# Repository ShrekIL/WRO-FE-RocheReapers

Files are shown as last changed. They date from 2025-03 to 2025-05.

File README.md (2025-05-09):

#   RocheReapers Future Engineers Team

<p align="center">
  banner
</p>

This repository contains all the code and documentation of the WRO Team `RocheReapers`

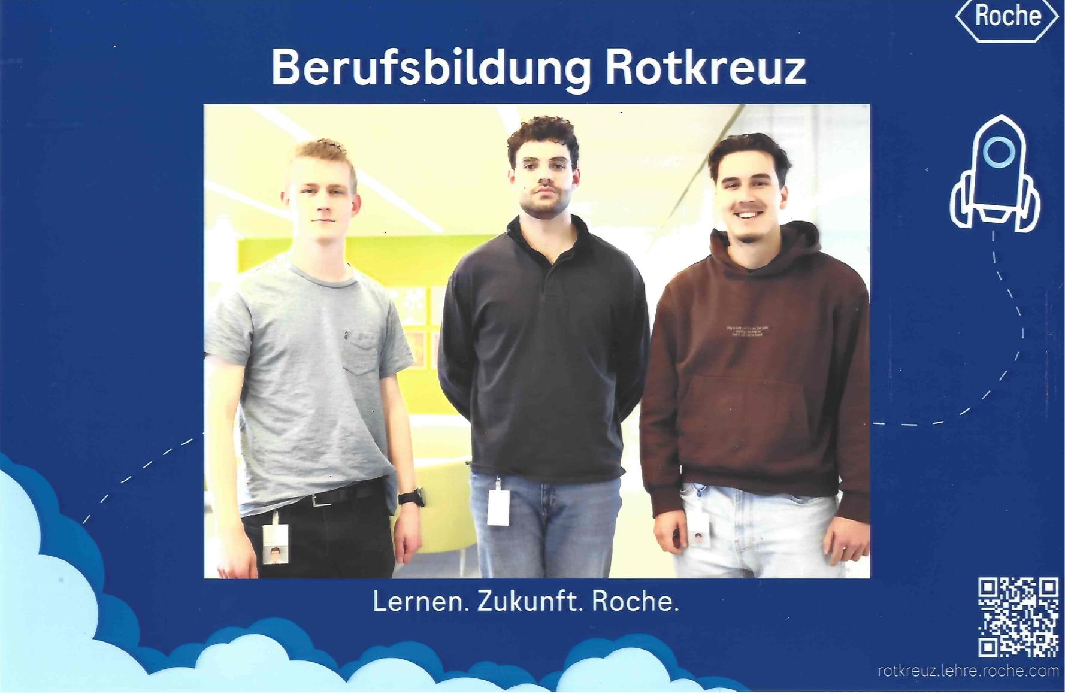
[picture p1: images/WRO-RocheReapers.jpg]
team_photo


**Team Members:**
\* [Robin Küttel](https://github.com/Robinkuet1): [robinkuettel@gmail.com](mailto:robinkuettel@gmail.com)
\* [Guilherme Vercillo Fortes](https://github.com/vercillg)
\* [Mischa Fässler](https://github.com/ShrekIL)

**Coach:**
\* Cyril Odermatt

##   Description of the developed solution

###   1. Problem Statement and Goal
The goal of the competition is to develop an autonomous vehicle that can complete two challenges:

-   Open Challenge: Three laps on a area of known size, but with a obstacle of unknown dimensions in the center.

-   Obstacle Challenge: Three laps with colored obstacles and a parallel parking maneuver in a parking zone on a 3x3 area.
    -   When <span style="color:red">red</span> obstacle =\> turn right
    -   When <span style="color:green">green</span> obstacle =\> turn left
    -   Parking zone colored with <span style="color:magenta">magenta</span>

---

###   2. Hardware Overview
The vehicle is based on the Hiwonder MentorPi A1.

####   Vehicle Photos

Below are the vehicle images from different perspectives.

<p align="center">
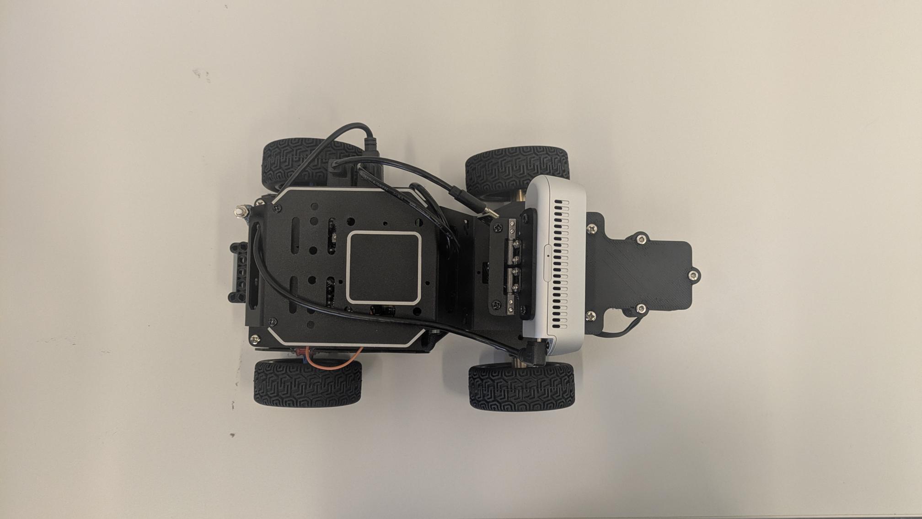
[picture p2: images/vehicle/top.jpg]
Top View

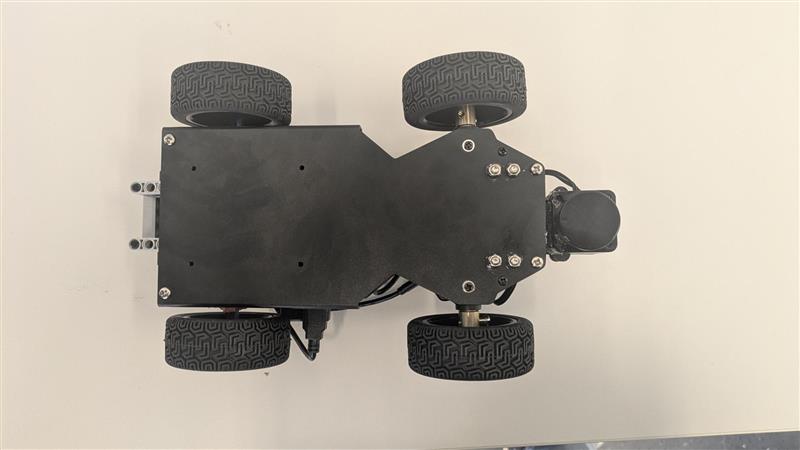
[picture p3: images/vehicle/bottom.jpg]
Bottom View

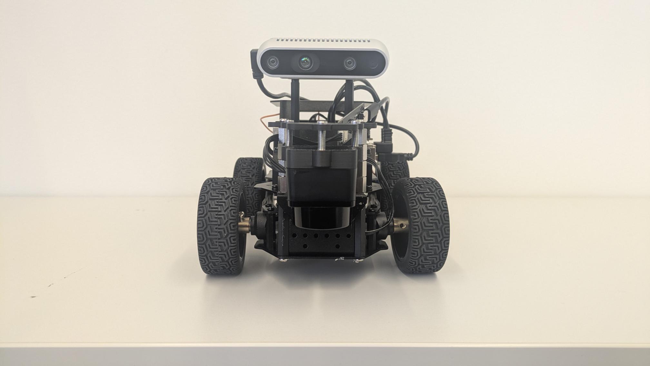
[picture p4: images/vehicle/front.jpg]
Front View

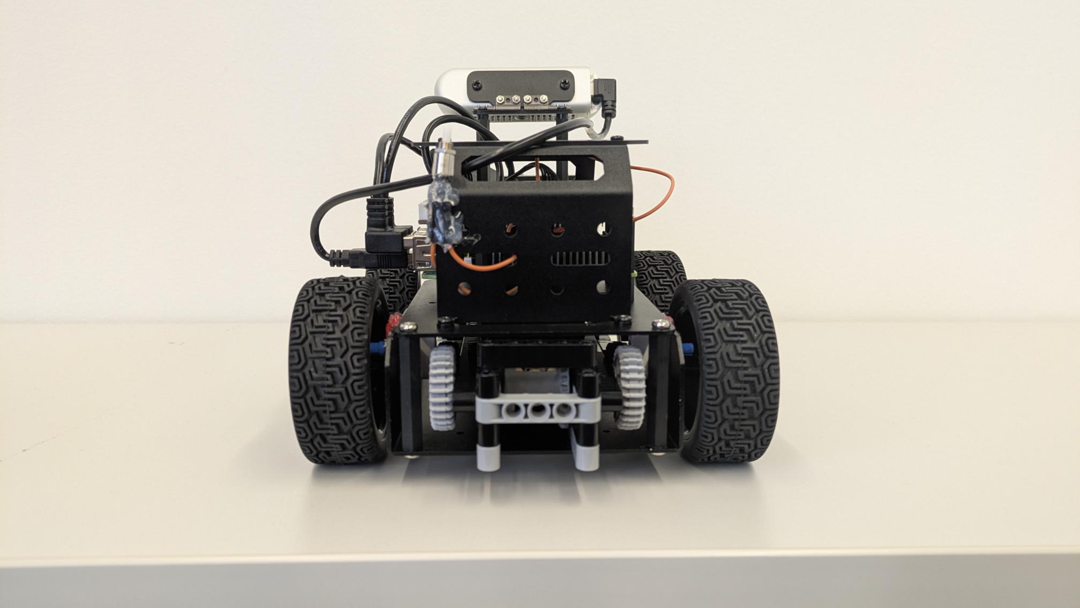
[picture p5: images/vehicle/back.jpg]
Back View

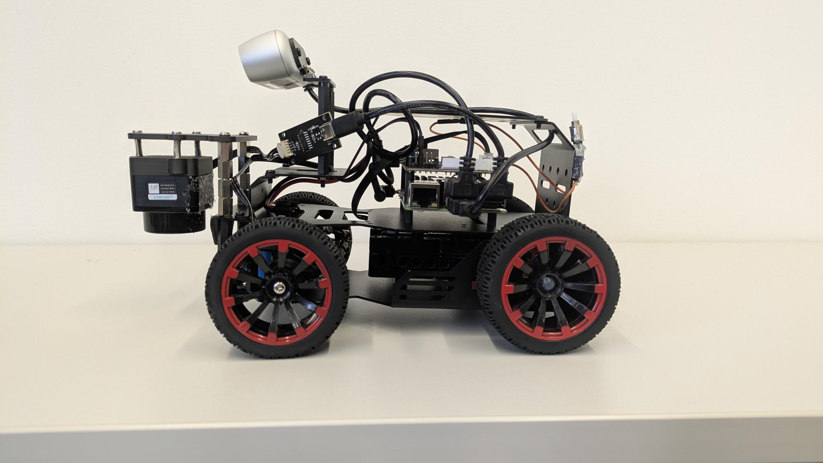
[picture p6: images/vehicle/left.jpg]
Left View

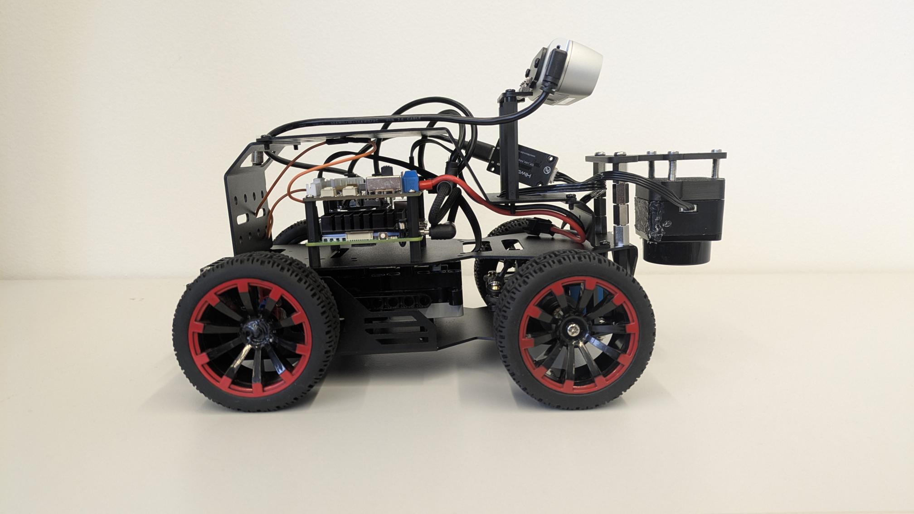
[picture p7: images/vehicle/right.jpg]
Right View

</p>

####   Hardware changes
We made the following hardware changes:

-   To comply with WRO rules, one motor was removed, so the drive is now powered by a single motor mechanically coupled to a LEGO differential gear. It also had to be stabilised with a lego construct for exact power output to the rear wheels.
-   The originally installed 3D camera was replaced with an Intel RealSense D435i to achieve a better performance. The brightness/colors of the original camera were too upredictable and thus not well suited for computer vision
-   The LiDAR sensor was relocated to the front of the vehicle, as the walls are only 10cm high. So the lidar is now at about 5cm above ground, for the highest possible chance to detect all the visible walls.
    -   Due to the repositioning of the LiDAR sensor, the camera's mounting height also had to be adjusted to maintain an unobstructed field of view. This was achieved by slightly elevating the camera using a custom riser.
-   The standard servo motor responsible for steering was replaced with a Power HD LW-15MG (waterproof) to significantly improve performance. The upgrade increased the control frequency from the standard 50 Hz to 333 Hz, resulting in faster and more precise steering response.
-   A simple push button was added to start the robot

####   Dimensions

| Parameter | Value |
|---:|---|
| Weight | 1.2 kg (on 3 attempts) |
| Height | 16.5 cm |
| Length | 28 cm |
| Width | 16.5 cm |

####   Lidar mounting
At first we tried to mount the lidar using hot glue. This didn't work well.
Due to the walls only beeing 10cm high and the lidar beeing mounted 5cm from the ground, we had 5cm of tolerance on a 3m distance.
If we calculate the anlge tolerance with trigonometry we get the following:

$sin(Tolerance) \* 3 = 0.05m$

If we solve this equation we arrive at:

$Tolerance\approx +-0.9549\textdegree$

We realized, that this is basically impossible to achieve with hot glue, we decided to design our own mounting mechanism.
For this we 3d printed a mount, that can be adjusted using 3 screws.

See following picture:

<p align="center">
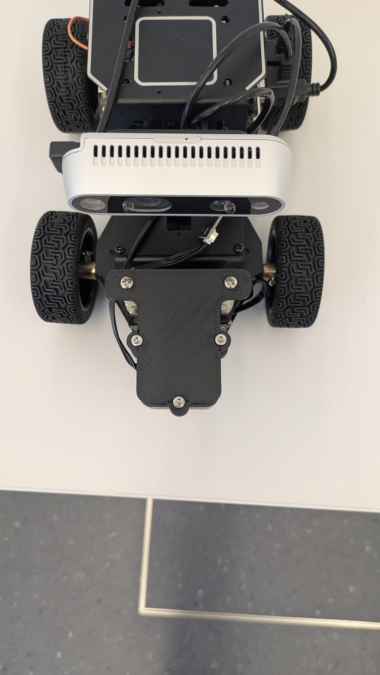
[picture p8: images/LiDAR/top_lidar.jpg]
top_lidar

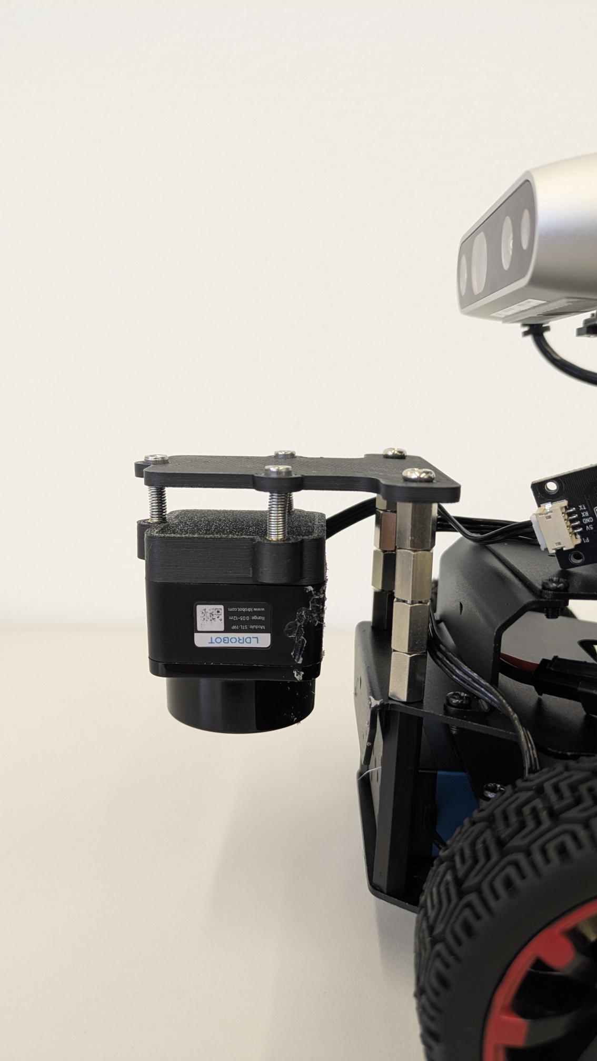
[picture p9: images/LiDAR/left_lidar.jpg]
left_lidar

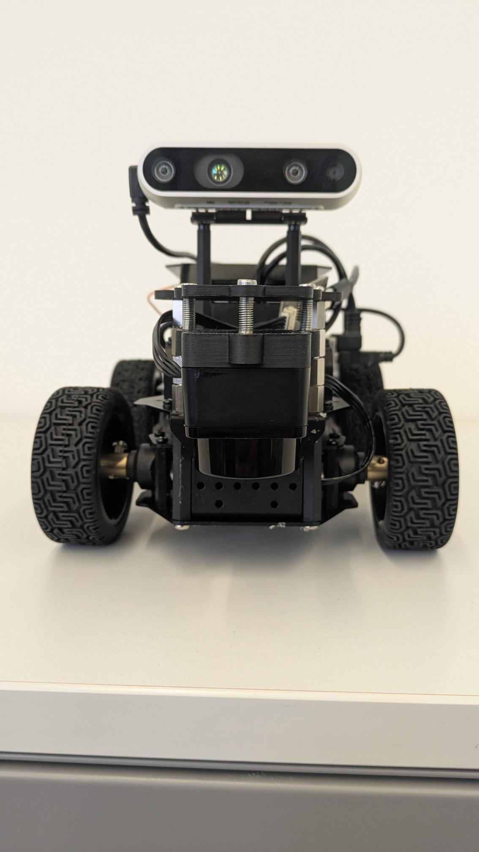
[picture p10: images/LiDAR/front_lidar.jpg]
front_lidar

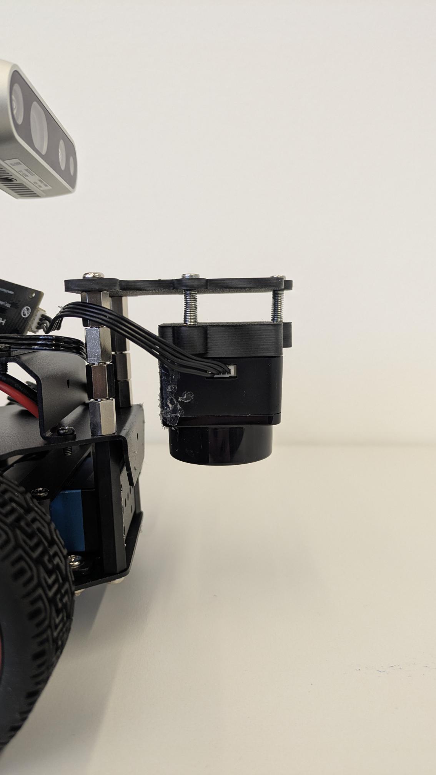
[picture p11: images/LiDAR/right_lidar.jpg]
right_lidar

<p>

With this, we were now able to accurately callibrate the lidar.

####   Lego differential gearbox

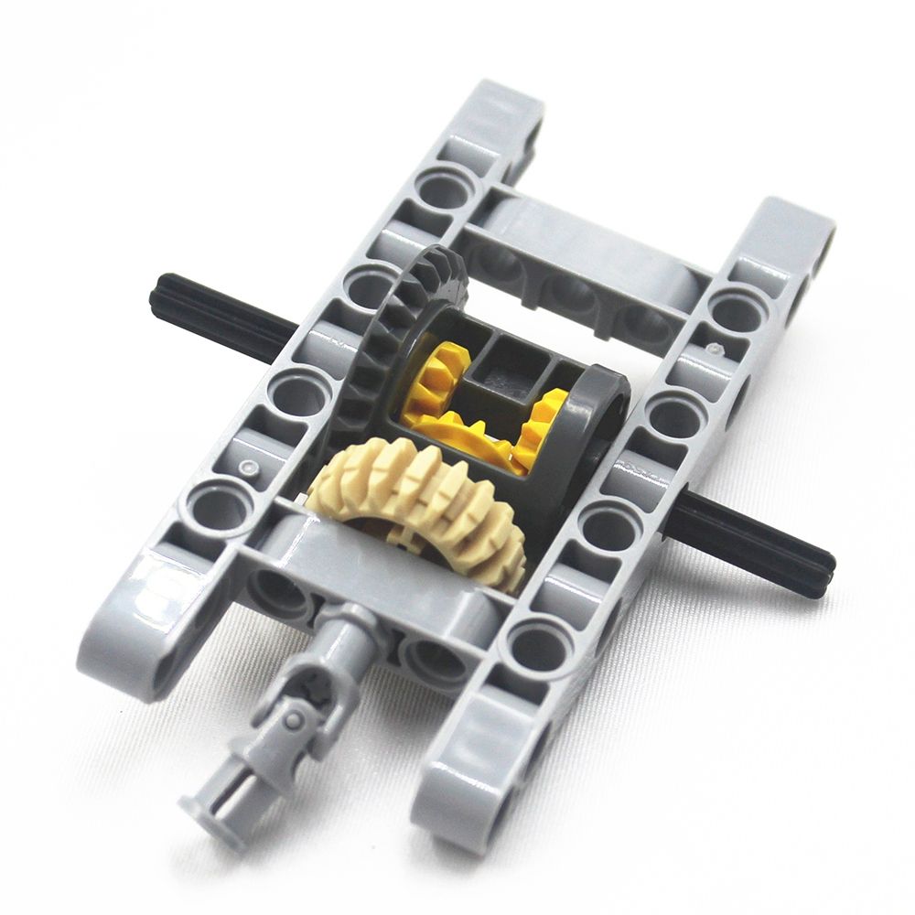
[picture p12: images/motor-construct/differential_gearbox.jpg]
differential_gearbox


Since the vehicle is now powered by a single motor, the use of a differential gearbox was essential. This allows the rear wheels to rotate at different speeds during turns, improving the robot's maneuverability and stability. The Lego construction was also stabilized to ensure precise and even power transmission to both rear wheels.

See following picture:

<p align="center">
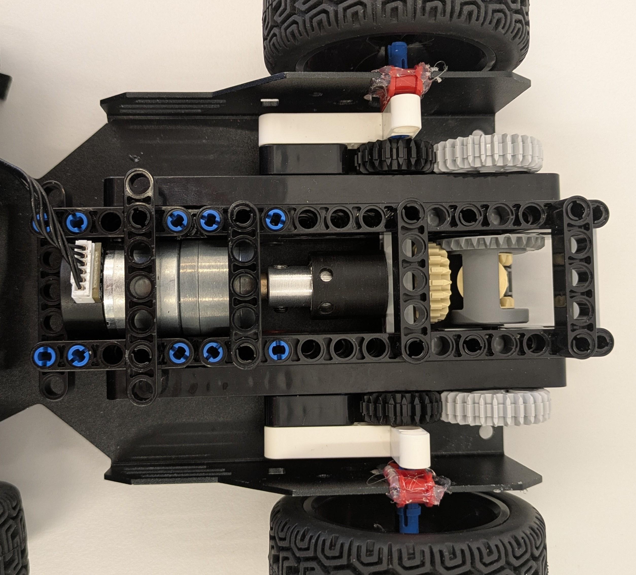
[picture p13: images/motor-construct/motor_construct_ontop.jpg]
motor_construct_ontop

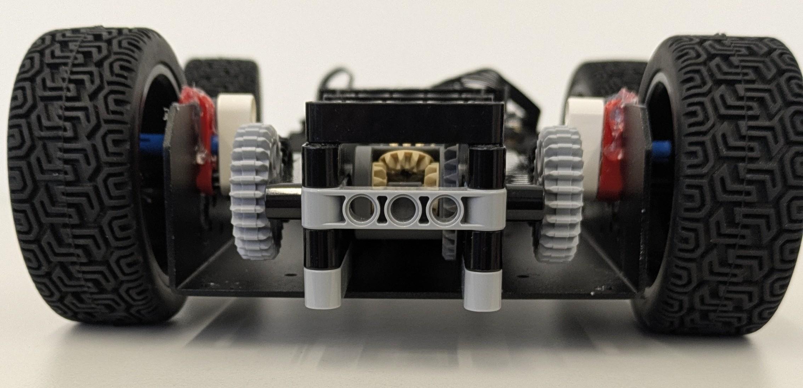
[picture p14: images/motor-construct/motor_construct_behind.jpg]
motor_construct_behind

<p>

####   Sensor Overview
| Component | Type/Model | Position on Robot | Function |
|---|---|---|---|
| 3D Camera | Intel RealSense D435i | Front (raised mount) | Color detection (OpenCV), depth sensing |
| LiDAR | STL-19P TOF Lidar | Front, 5 cm above ground | Obstacle/wall detection, navigation |
| Steering Servo | Power HD LW-15MG | Front axle | Controls steering (PWM, 333 Hz) |
| Drive Motor | Hiwonder DC Motor | Rear, center | Drives the vehicle via LEGO differential |
| Start Button | Generic Push Button | Top back left of chassis | Starts the program |

---

###   3. Software Overview

Our software works based on states that follow simple rules.

See the following diagram for an overview of the possible states:

```mermaid
stateDiagram-v2
[*] --> Ready
Ready --> Moving
Moving --> Turning
Turning --> Moving

Moving --> BackingUp
BackingUp --> Moving

Moving --> Parking
Moving --> [*]

Parking --> [*]
```

**Explanation of the states**:

**Ready**: The state right after powering the robot on. It waits and does nothing until the start button is pressed. Then the robot switches to the moving state.

**Moving**: This is the main state of the robot. In this state the robot just uses the lidar data to move around the 3x3 area.
In case a obstace is detected, the robot automatically starts turning into the direction corresponding to the color of the obstacle.
Whenever the distance of the robot to a wall in front gets below a certain threshold, it changes to the turning state.

**Turning**: In this state, the robot is turning in to the direction, where the wall is farther away.
As soon as the angle to the wall at the side and the front is close to 90deg, the state changes back to Moving.

**BackingUp**: In this state, the robot will try to move away from an obstacle while trying to turn a bit, so it is easier to pass the obstace when driving forward again.

####   Obstacle detection with OpenCV

**Goal**

To provide the robot with the capability to visually identify and locate red and green blocks, specifically for the **Obstacle Challenge.**
This supplements the LiDAR-based navigation used in the **Open Challenge** by adding color-based object recognition.

**Why OpenCV for this Task?**

**Color as a Key Feature**

The challenge involves colored obstacles. OpenCV allows us to easily isolate objects based on their color, providing a direct and efficient way to identify the target blocks.

**Complementary Sensing**
While LiDAR excels at distance measurement and obstacle avoidance, OpenCV provides semantic information about the type of obstacle (based on color).
Combining these sensor inputs allows for a more nuanced understanding of the environment.

**How it Integrates with the Robot's Software**

The OpenCV-based obstacle detection likely operates as a module within the robot's overall software architecture. It would:

-   **Process Images from the RealSense Camera:**
    The RealSense D435i, chosen for its improved color accuracy, provides the visual data that OpenCV analyzes.

-   **Identify Red and Green Regions:**
    Using the techniques described earlier (color space conversion, thresholding), OpenCV identifies areas in the image that match the defined red and green color ranges.

-   **Locate and Characterize Blocks:**
    By finding the contours of these colored regions, OpenCV can determine the position (in the image) and size of potential blocks. The color of each detected block can also be determined based on the dominant color within its contour.

-   **Provide Information to the Robot's State Machine:**
    The information about the detected blocks (their color, position, and size) is then likely passed to the robot's state machine.
    This allows the robot to make decisions and transition between states based on what it "sees."
    For example, upon detecting a green block in a specific area, the robot might initiate the parallel parking maneuver.

**Synergy with Other Sensors**

It’s important to note how the OpenCV-based detection works in conjunction with the LiDAR:

-   **LiDAR for General Obstacle Avoidance:**
    The LiDAR likely handles the primary task of navigating the 3×3 area and avoiding any unforeseen obstacles during both challenges.

-   **OpenCV for Color-Specific Tasks:**
    When the **"Obstacle Challenge"** requires interaction with colored blocks, OpenCV provides the necessary color identification capability that LiDAR alone cannot offer.

---

By integrating OpenCV for color-based object detection with the LiDAR for spatial awareness, the **RocheReapers' robot** gains a more comprehensive understanding of its environment, enabling it to tackle the complexities of both competition challenges effectively.

####   Development Tools & Libraries/SDKs

**Development Tools:**

-   **VS Code:** A widely used, free, and extensible code editor utilized for various programming languages and development tasks.

-   **PyCharm:** A dedicated Integrated Development Environment (IDE) specifically designed for Python development, offering advanced features for coding assistance, debugging, testing, and project management.

-   **Git:** A distributed version control system frequently used in software development to manage code changes and facilitate team collaboration. VS Code, for example, offers good integration with Git.

-   **GitHub:** A web-based hosting service for version control using Git that provides collaboration features such as bug tracking, feature requests, task management, and continuous integration. Used for sharing and collaborating on the robot's codebase.

-   **Intel RealSense Viewer:** A graphical tool for visualizing and configuring Intel RealSense depth cameras. It enables the display of depth, color, and infrared data, as well as the adjustment of camera settings.

-   **ROS (Robot Operating System):** A flexible framework for writing robot software. It provides a collection of tools, libraries, and conventions that aim to simplify the task of creating complex and robust robot behavior across a wide variety of robotic platforms. ROS often integrates with sensors like the Intel RealSense cameras.

-   **Linux:** A family of open-source Unix-like operating systems. It is known for its flexibility, customizability, and use in various applications, including development and server environments.

-   **Windows:** A series of graphical operating systems developed by Microsoft. It is widely used on personal computers and in enterprise environments.

-   **RealVNC Viewer:** A software application that allows you to control a remote computer over the network (can be used for remote development or accessing development environments).

**Libraries/SDKs:**

-   **Python:** A versatile and widely-used programming language in robotics for scripting, algorithm development, and integration with sensors and systems.

-   **OpenCV (`cv2`):** An open-source computer vision library used for image processing, object detection, and interfacing with camera streams.

-   **NumPy:** A powerful library for numerical operations on arrays, commonly used for image and sensor data processing.

-   **Matplotlib:** A plotting library used to visualize sensor data, debugging outputs, or robot trajectories during development.

-   **pyrealsense2:** Intel’s official Python wrapper for the librealsense SDK, used to interface with RealSense cameras for depth and RGB image capture.

-   **librealsense SDK:** A cross-platform library to interact with Intel RealSense cameras, including features like point cloud generation, depth alignment, and sensor fusion.

-   **pytest:** A testing framework for writing and running automated tests on Python code, useful for maintaining stable control and perception modules.

-   **ROS 2 Message Types & Services:**
    -   `sensor_msgs`, `geometry_msgs`, `std_srvs`, `ros_robot_controller_msgs`: ROS interfaces used for sensor data (e.g., images, laser scans), robot movement (Twist messages), service requests (e.g., enable/disable modules), and PWM servo control.

###   Videos
https://youtu.be/dnrOrvzk_1k?si=iM_9Jk8Tol_acwze

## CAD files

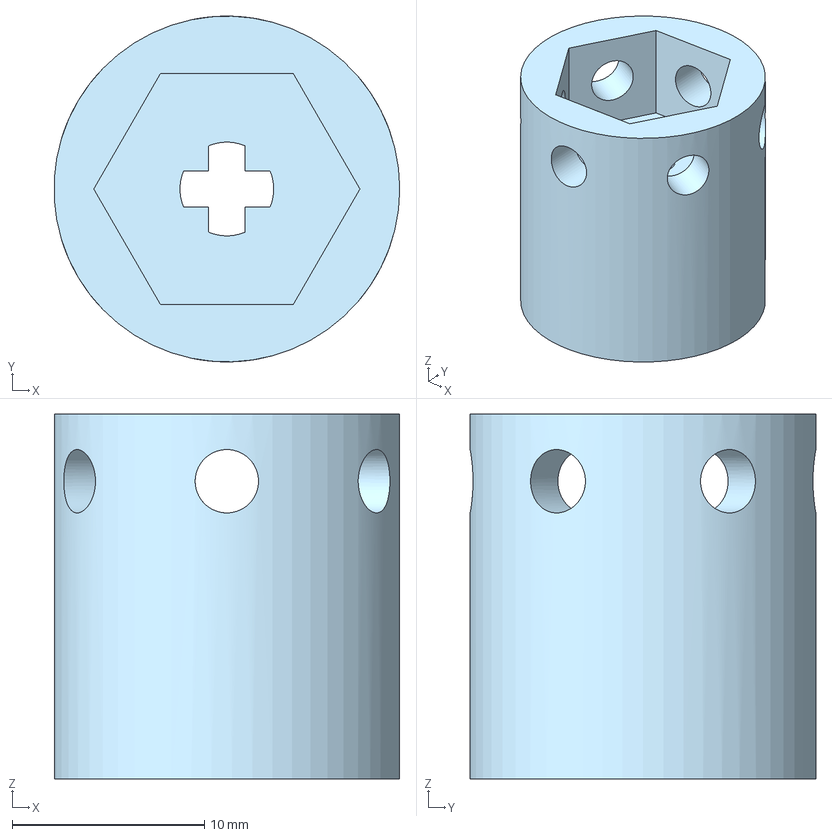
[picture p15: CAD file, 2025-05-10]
3d_models/Adapter_motorachse.step
18.0 x 18.0 x 19.0 mm

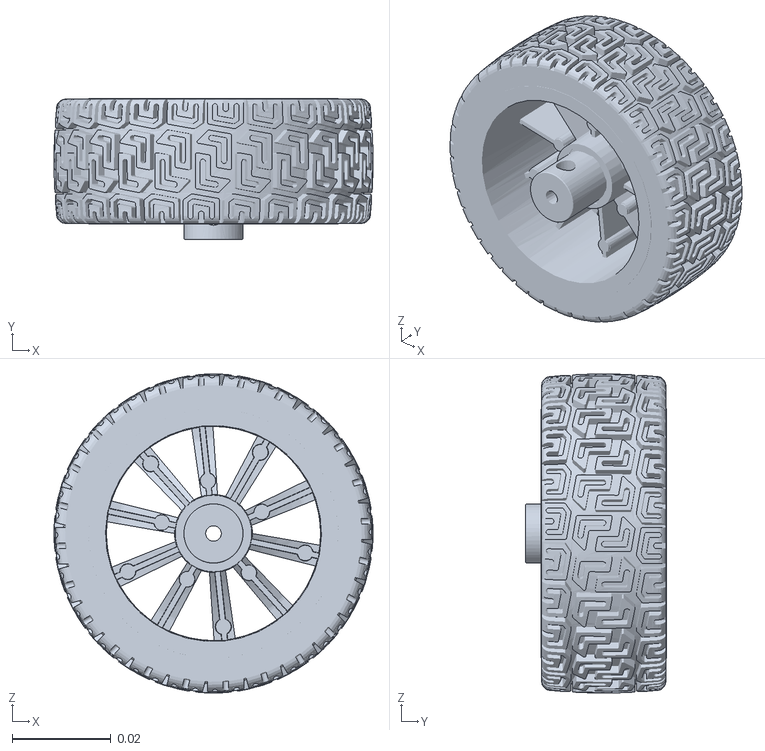
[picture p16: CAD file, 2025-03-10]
src/simulations/mentorpi_description/meshes/acker/wheel_lb_Link.STL
0.0647 x 0.0285 x 0.0647

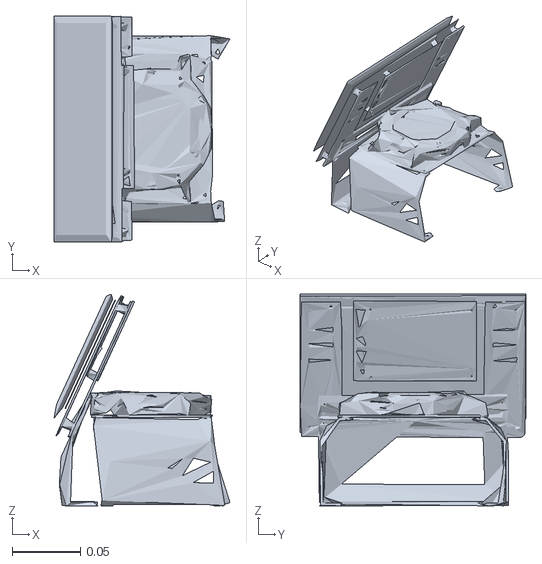
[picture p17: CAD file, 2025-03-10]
src/simulations/mentorpi_description/meshes/common/back_shell_black_link_collision.stl
0.129 x 0.165 x 0.155

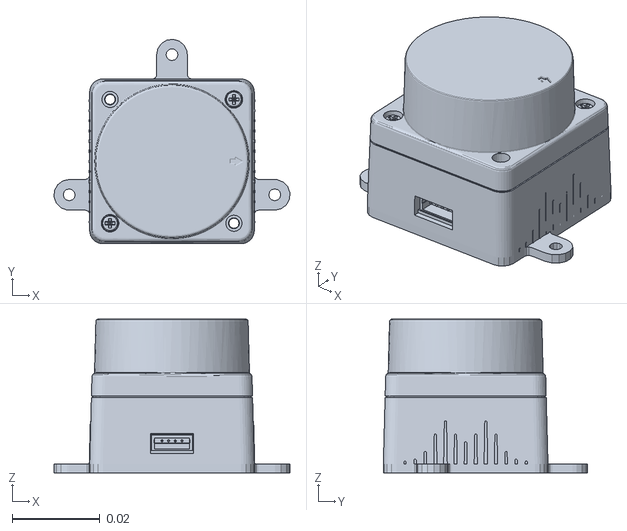
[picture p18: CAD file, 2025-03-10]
src/simulations/mentorpi_description/meshes/mecanum/lidar_Link.STL
0.0537 x 0.0465 x 0.035

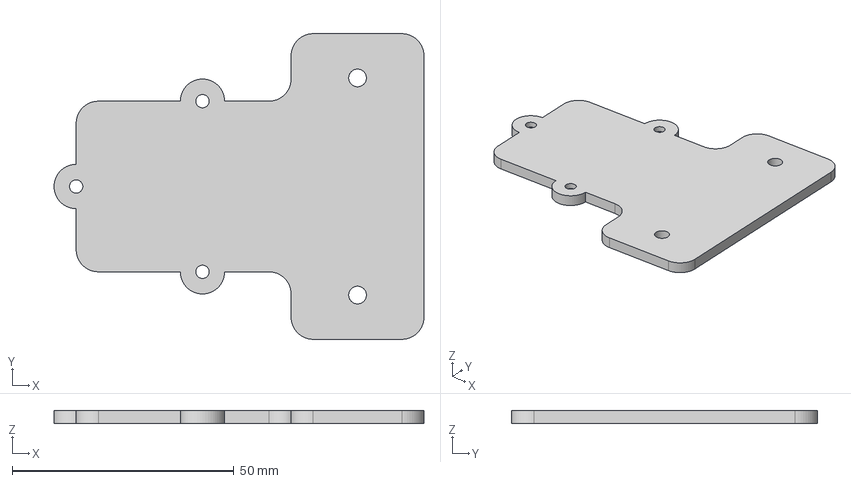
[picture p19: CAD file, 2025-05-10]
3d_models/LidarMountingPlate.step
83.5 x 69.0 x 3.00 mm

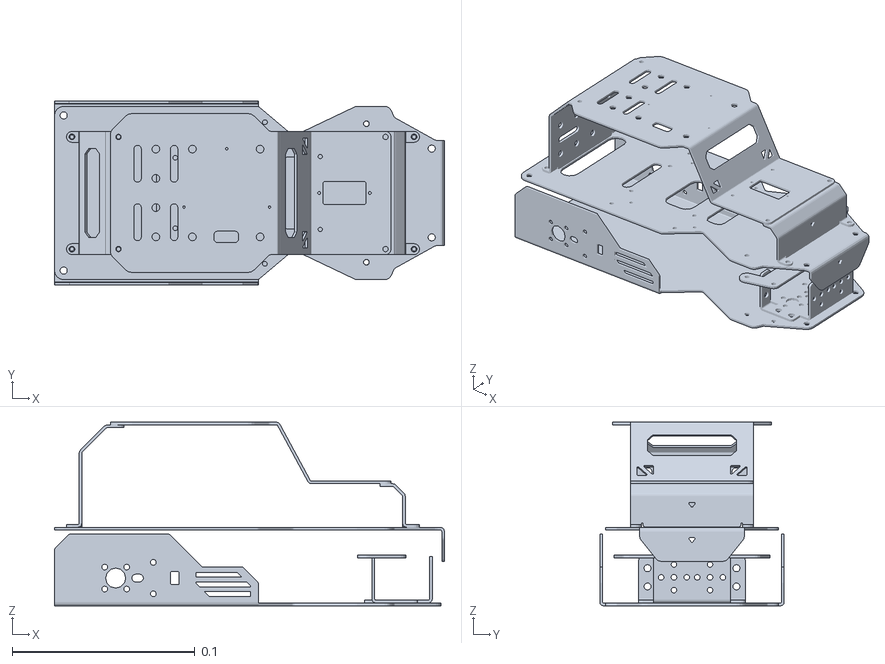
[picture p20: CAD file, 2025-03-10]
src/simulations/mentorpi_description/meshes/acker/base_link.STL
0.213 x 0.101 x 0.101

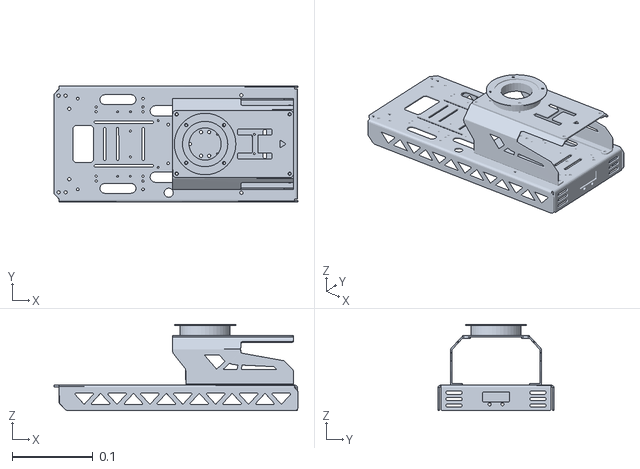
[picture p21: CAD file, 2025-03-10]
src/simulations/mentorpi_description/meshes/common/back_shell_green_link.stl
0.303 x 0.144 x 0.107

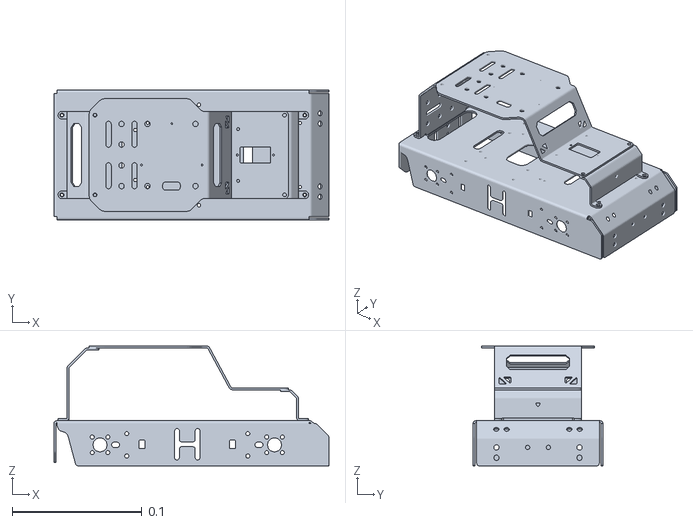
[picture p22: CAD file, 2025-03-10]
src/simulations/mentorpi_description/meshes/mecanum/base_link.STL
0.212 x 0.1 x 0.0924

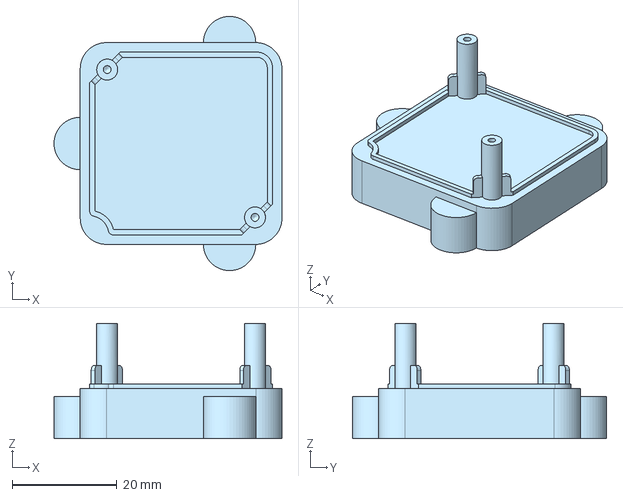
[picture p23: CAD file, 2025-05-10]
3d_models/ReplacementBasePlateLidar.step
43.5 x 48.5 x 22.0 mm

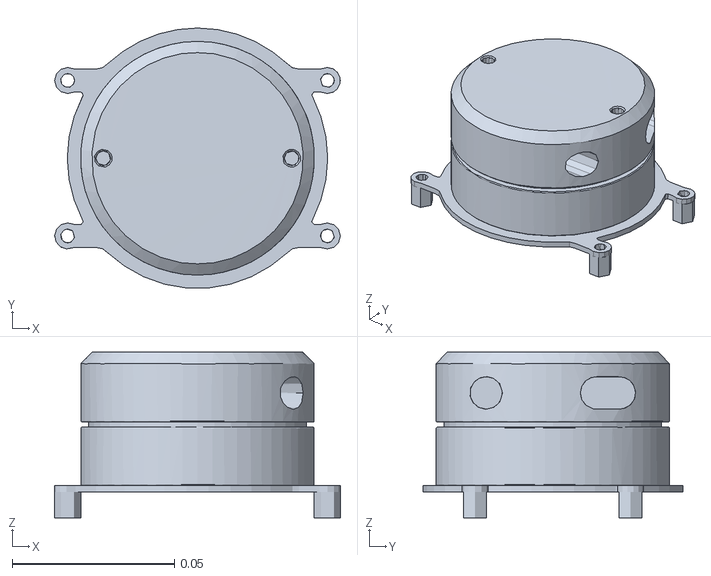
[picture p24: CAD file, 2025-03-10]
src/simulations/mentorpi_description/meshes/common/lidar_link.stl
0.0881 x 0.08 x 0.0511

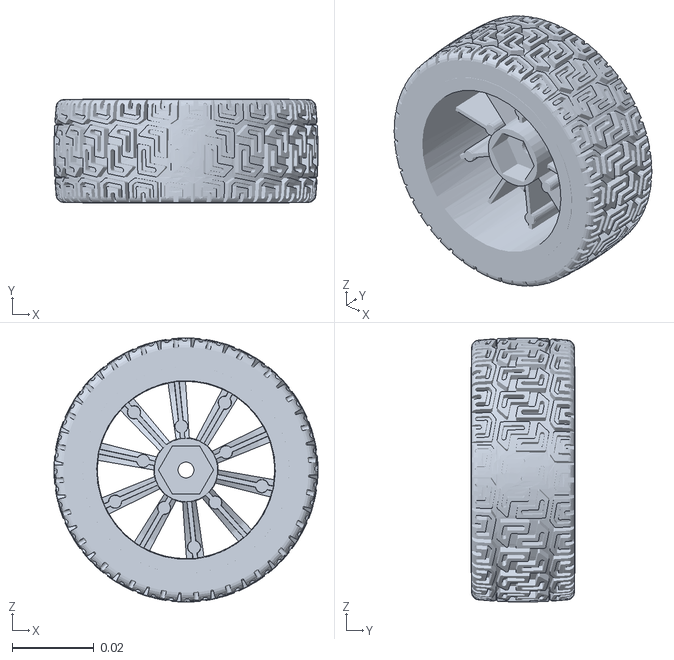
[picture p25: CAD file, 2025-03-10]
src/simulations/mentorpi_description/meshes/acker/wheel_lf_Link.STL
0.0647 x 0.0254 x 0.0647

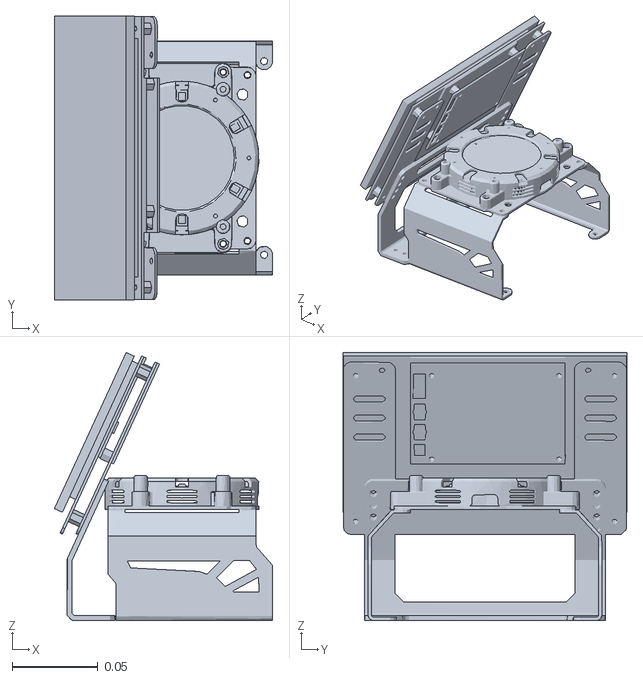
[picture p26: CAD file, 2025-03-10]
src/simulations/mentorpi_description/meshes/common/back_shell_black_link.stl
0.127 x 0.165 x 0.156

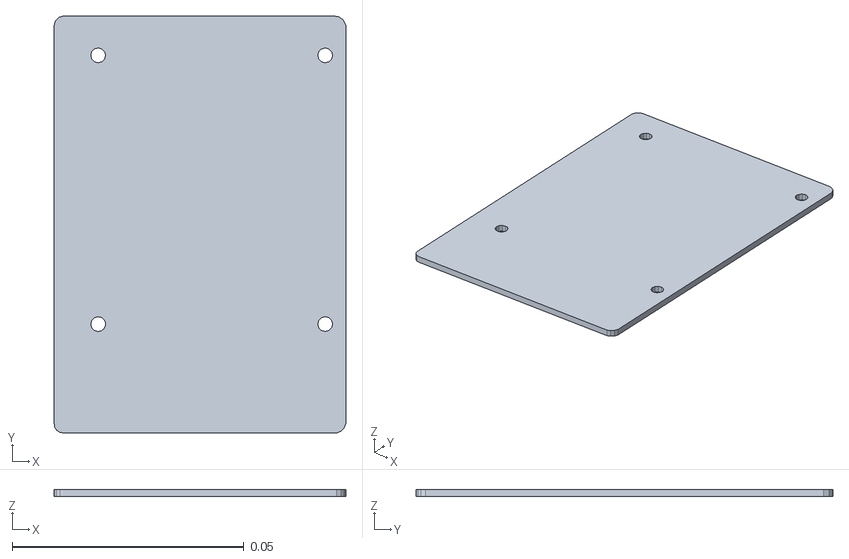
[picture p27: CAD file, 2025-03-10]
src/simulations/mentorpi_description/meshes/acker/imu_link.stl
0.063 x 0.09 x 0.0016

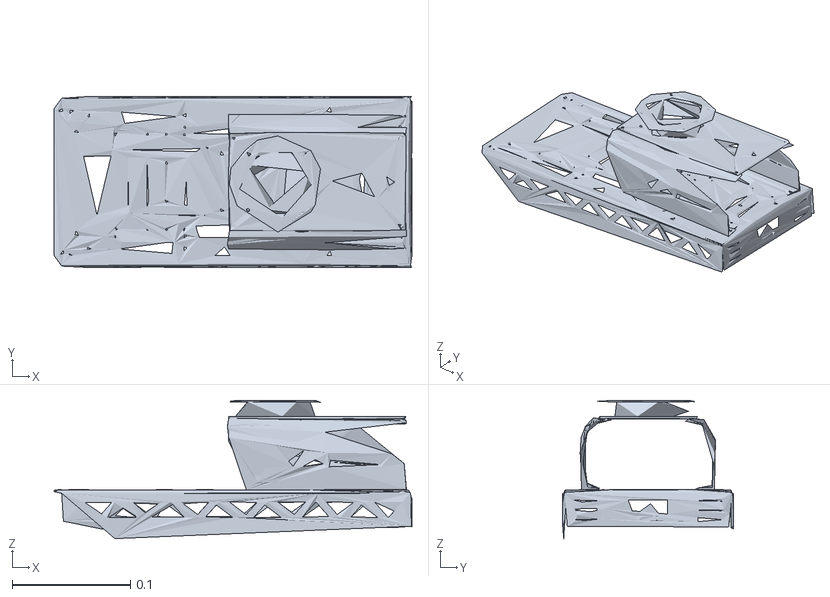
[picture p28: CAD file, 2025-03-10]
src/simulations/mentorpi_description/meshes/common/back_shell_green_link_collision.stl
0.302 x 0.144 x 0.117

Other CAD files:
src/simulations/mentorpi_description/meshes/acker/lidar_Link.STL
src/simulations/mentorpi_description/meshes/acker/wheel_rf_Link.STL
src/simulations/mentorpi_description/meshes/acker/wheel_rb_Link.STL
3d_models/LidarMountingPlate.stl
3d_models/ReplacementBasePlateLidar.stl

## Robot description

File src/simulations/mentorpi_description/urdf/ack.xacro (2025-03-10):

<?xml version="1.0" ?>
<robot name="ack" xmlns:xacro="http://ros.org/wiki/xacro">
    <!-- 瀹氫箟榛戣壊鏉愯川 -->
  <material name="black">
    <color rgba="0 0 0 1"/>
  </material>
  <!-- 瀹氫箟 base_link -->
  <link name="base_link">
    <inertial>
      <origin rpy="0 0 0" xyz="-0.00186669751054189 3.0253386351986E-05 -0.00605296088229322"/>
      <mass value="0.0961047465616957"/>
      <inertia ixx="8.55867486364231E-05" ixy="3.41346959938296E-08" ixz="1.64755227278164E-05" iyy="0.000277248181555496" iyz="-2.95282759133104E-08" izz="0.000344246448853775"/>
    </inertial>
    <visual>
      <origin rpy="0 0 0" xyz="0 0 0"/>
      <geometry>
        <mesh filename="package://mentorpi_description/meshes/acker/base_link.STL"/>
      </geometry>
      <material name="">
        <color rgba="1 1 1 1"/>
      </material>
    </visual>
    <collision>
      <origin rpy="0 0 0" xyz="0 0 0"/>
      <geometry>
        <mesh filename="package://mentorpi_description/meshes/acker/base_link.STL"/>
      </geometry>
    </collision>
  </link>

  <!-- 娣诲姞 base_footprint 閾炬帴 -->
  <link name="base_footprint"/>

  <!-- 瀹氫箟 base_footprint 鍒?base_link 鐨勫浐瀹氬叧鑺?-->
  <joint name="base_footprint_to_base_link" type="fixed">
    <parent link="base_footprint"/>
    <child link="base_link"/>
    <origin xyz="0 0 0.07" rpy="0 0 0"/>
  </joint>

  <!-- 瀹氫箟鍏朵粬閾炬帴鍜屽叧鑺?-->
  <link name="wheel_lf_Link">
    <inertial>
      <origin rpy="0 0 0" xyz="1.65897579444685E-06 -0.00270913022688685 -1.5546673051009E-06"/>
      <mass value="0.0252873083503169"/>
      <inertia ixx="1.00371783485335E-05" ixy="4.93900109379125E-11" ixz="7.42104604492639E-10" iyy="1.67620175120314E-05" iyz="-5.47583950457701E-11" izz="1.00370342405297E-05"/>
    </inertial>
    <visual>
      <origin rpy="0 0 0" xyz="0 0 0"/>
      <geometry>
        <mesh filename="package://mentorpi_description/meshes/acker/wheel_lf_Link.STL"/>
      </geometry>
      <material name="">
        <color rgba="1 1 1 1"/>
      </material>
    </visual>
    <collision>
      <origin rpy="0 0 0" xyz="0 0 0"/>
      <geometry>
        <mesh filename="package://mentorpi_description/meshes/acker/wheel_lf_Link.STL"/>
      </geometry>
    </collision>
  </link>
  <joint name="wheel_lf_Joint" type="continuous">
    <origin rpy="0 0 0" xyz="0.06679 0.069739 -0.0288"/>
    <parent link="base_link"/>
    <child link="wheel_lf_Link"/>
    <axis xyz="-2.2918E-05 1 1.9551E-05"/>
  </joint>

  <link name="wheel_rf_Link">
    <inertial>
      <origin rpy="0 0 0" xyz="-1.48986965733955E-06 0.0027090575018239 1.16299057125596E-06"/>
      <mass value="0.0252873548617242"/>
      <inertia ixx="1.00360241846408E-05" ixy="-5.83065201444192E-11" ixz="-8.3023958781985E-11" iyy="1.67622954977732E-05" iyz="6.31638512668579E-11" izz="1.00384960556047E-05"/>
    </inertial>
    <visual>
      <origin rpy="0 0 0" xyz="0 0 0"/>
      <geometry>
        <mesh filename="package://mentorpi_description/meshes/acker/wheel_rf_Link.STL"/>
      </geometry>
      <material name="">
        <color rgba="1 1 1 1"/>
      </material>
    </visual>
    <collision>
      <origin rpy="0 0 0" xyz="0 0 0"/>
      <geometry>
        <mesh filename="package://mentorpi_description/meshes/acker/wheel_rf_Link.STL"/>
      </geometry>
    </collision>
  </link>
  <joint name="wheel_rf_Joint" type="continuous">
    <origin rpy="0 0 0" xyz="0.066794 -0.069739 -0.028803"/>
    <parent link="base_link"/>
    <child link="wheel_rf_Link"/>
    <axis xyz="-2.2918E-05 1 1.9551E-05"/>
  </joint>

  <link name="wheel_lb_Link">
    <inertial>
      <origin rpy="0 0 0" xyz="1.62806317080544E-06 -0.00317716794378092 -1.54238045318306E-06"/>
      <mass value="0.0271078161230754"/>
      <inertia ixx="1.01056035703468E-05" ixy="4.60479373806495E-11" ixz="7.43896782806142E-10" iyy="1.67990600599721E-05" iyz="-5.763890541079E-11" izz="1.01072652738793E-05"/>
    </inertial>
    <visual>
      <origin rpy="0 0 0" xyz="0 0 0"/>
      <geometry>
        <mesh filename="package://mentorpi_description/meshes/acker/wheel_lb_Link.STL"/>
      </geometry>
      <material name="">
        <color rgba="1 1 1 1"/>
      </material>
    </visual>
    <collision>
      <origin rpy="0 0 0" xyz="0 0 0"/>
      <geometry>
        <mesh filename="package://mentorpi_description/meshes/acker/wheel_lb_Link.STL"/>
      </geometry>
    </collision>
  </link>
  <joint name="wheel_lb_Joint" type="continuous">
    <origin rpy="0 0 0" xyz="-0.070313 0.07014 -0.027793"/>
    <parent link="base_link"/>
    <child link="wheel_lb_Link"/>
    <axis xyz="-2.2787E-05 1 1.9439E-05"/>
  </joint>

  <link name="wheel_rb_Link">
    <inertial>
      <origin rpy="0 0 0" xyz="-1.50804700475154E-06 0.00317707027691583 1.18963606317302E-06"/>
      <mass value="0.0271078005024283"/>
      <inertia ixx="1.01044417409685E-05" ixy="-5.83069005452564E-11" ixz="-7.56886841840775E-11" iyy="1.67993271276785E-05" iyz="6.31638424138502E-11" izz="1.01087182681654E-05"/>
    </inertial>
    <visual>
      <origin rpy="0 0 0" xyz="0 0 0"/>
      <geometry>
        <mesh filename="package://mentorpi_description/meshes/acker/wheel_rb_Link.STL"/>
      </geometry>
      <material name="">
        <color rgba="1 1 1 1"/>
      </material>
    </visual>
    <collision>
      <origin rpy="0 0 0" xyz="0 0 0"/>
      <geometry>
        <mesh filename="package://mentorpi_description/meshes/acker/wheel_rb_Link.STL"/>
      </geometry>
          </collision>
  </link>
  <joint name="wheel_rb_Joint" type="continuous">
    <origin rpy="0 0 0" xyz="-0.07031 -0.07014 -0.027796"/>
    <parent link="base_link"/>
    <child link="wheel_rb_Link"/>
    <axis xyz="-2.2787E-05 1 1.9439E-05"/>
  </joint>

  <link name="depth_cam">
    <inertial>
      <origin rpy="0 0 0" xyz="0.0023402290651429 0.00113784597946548 -0.0102127064032341"/>
      <mass value="0.0270474748429678"/>
      <inertia ixx="1.43718505822118E-05" ixy="1.24779382573379E-07" ixz="1.29836477956744E-08" iyy="1.65912768209848E-06" iyz="2.28291478579102E-08" izz="1.45615925510082E-05"/>
    </inertial>
    <visual>
      <origin rpy="0 0 0" xyz="0 0 0"/>
      <geometry>
        <mesh filename="package://mentorpi_description/meshes/acker/cam_Link.STL"/>
      </geometry>
      <material name="">
        <color rgba="1 1 1 1"/>
      </material>
    </visual>
    <collision>
      <origin rpy="0 0 0" xyz="0 0 0"/>
      <geometry>
        <mesh filename="package://mentorpi_description/meshes/acker/cam_Link.STL"/>
      </geometry>
    </collision>
  </link>
  <joint name="cam_Joint" type="fixed">
    <origin rpy="0 0 0" xyz="0.064015 -0.00013463 0.051155"/>
    <parent link="base_link"/>
    <child link="depth_cam"/>
    <axis xyz="0 0 0"/>
  </joint>

  <link name="lidar_frame">
    <inertial>
      <origin rpy="0 0 0" xyz="8.65086433231368E-05 9.02624784523964E-05 -0.0183546134614858"/>
      <mass value="0.0405423044068563"/>
      <inertia ixx="4.98470776877503E-06" ixy="-1.54076264166869E-07" ixz="2.05182706824286E-09" iyy="5.03926730822203E-06" iyz="1.1006285118993E-08" izz="8.25645669548359E-06"/>
    </inertial>
    <visual>
      <origin rpy="0 0 0" xyz="0 0 0"/>
      <geometry>
        <mesh filename="package://mentorpi_description/meshes/acker/lidar_Link.STL"/>
      </geometry>
      <material name="">
        <color rgba="1 1 1 1"/>
      </material>
    </visual>
    <collision>
      <origin rpy="0 0 0" xyz="0 0 0"/>
      <geometry>
        <mesh filename="package://mentorpi_description/meshes/acker/lidar_Link.STL"/>
      </geometry>
    </collision>
  </link>
  <joint name="lidar_Joint" type="fixed">
    <origin rpy="0 0 0" xyz="-0.0096019 -8.533E-05 0.092501"/>
    <parent link="base_link"/>
    <child link="lidar_frame"/>
    <axis xyz="0 0 0"/>
  </joint>
  <xacro:include filename="$(find mentorpi_description)/urdf/imu.urdf.xacro"/>
</robot>

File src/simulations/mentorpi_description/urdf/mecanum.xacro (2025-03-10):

<?xml version="1.0" ?>
<robot name="mecanum" xmlns:xacro="http://ros.org/wiki/xacro">
  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
  
  <link name="imu_link"/>
  
  <joint name="imu_joint" type="fixed">
    <parent link="base_link"/>
    <child link="imu_link"/>
    <origin xyz="0 0 0" rpy="0 0 -1.57"/>
  </joint>
  
  <link name="base_footprint"/>
  
  <joint name="base_footprint_to_base_link" type="fixed">
    <parent link="base_footprint"/>
    <child link="base_link"/>
    <origin xyz="0 0 0.07" rpy="0 0 0"/>
  </joint>
  <link name="base_link">
    <inertial>
      <origin rpy="0 0 0" xyz="7.82634169708696E-05 3.66518389137982E-05 0.0068167426737893"/>
      <mass value="0.080358044299185"/>
      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
    </inertial>
    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
  </link>
  
  
  <link name="wheel_lf_Link">
    <inertial>
      <origin rpy="0 0 0" xyz="6.23194347770945E-05 -0.00574614971695361 2.98597149463314E-05"/>
      <mass value="0.0378743634664218"/>
      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
    </inertial>
    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
  </link>
  <joint name="wheel_lf_Joint" type="continuous">
    <origin rpy="0 0 0" xyz="0.067052 0.07591 -0.018408"/>
    <parent link="base_link"/>
    <child link="wheel_lf_Link"/>
    <axis xyz="0.00012228 1 -4.0642E-05"/>
  </joint>
  <link name="wheel_rf_Link">
    <inertial>
      <origin rpy="0 0 0" xyz="6.22118237483121E-05 0.00574626671891662 2.98167804906255E-05"/>
      <mass value="0.0378687944527435"/>
      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
    </inertial>
    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
  </link>
  <joint name="wheel_rf_Joint" type="continuous">
    <origin rpy="0 0 0" xyz="0.067052 -0.07591 -0.018408"/>
    <parent link="base_link"/>
    <child link="wheel_rf_Link"/>
    <axis xyz="0.00012228 1 -4.0642E-05"/>
  </joint>
  <link name="wheel_lb_Link">
    <inertial>
      <origin rpy="0 0 0" xyz="-4.39089176767909E-05 -0.00574629427498616 3.59684108433914E-05"/>
      <mass value="0.0378689402752074"/>
      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
    </inertial>
    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
  </link>
  <joint name="wheel_lb_Joint" type="continuous">
    <origin rpy="0 0 0" xyz="-0.06764 0.07591 -0.018414"/>
    <parent link="base_link"/>
    <child link="wheel_lb_Link"/>
    <axis xyz="0 1 0"/>
  </joint>
  <link name="wheel_rb_Link">
    <inertial>
      <origin rpy="0 0 0" xyz="-6.2256559793028E-05 0.00574614092169209 2.96857054536206E-05"/>
      <mass value="0.0378742388937267"/>
      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
    </inertial>
    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
  </link>
  <joint name="wheel_rb_Joint" type="continuous">
    <origin rpy="0 0 0" xyz="-0.067621 -0.07591 -0.018408"/>
    <parent link="base_link"/>
    <child link="wheel_rb_Link"/>
    <axis xyz="0 1 0"/>
  </joint>
  <link name="depth_cam">
    <inertial>
      <origin rpy="0 0 0" xyz="0.0023402290706885 0.00113784597175737 -0.010212706399263"/>
      <mass value="0.0270474748712619"/>
      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
    </inertial>
    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
  </link>
  <joint name="cam_Joint" type="fixed">
    <origin rpy="0 0 0" xyz="0.061376 -0.00013463 0.051154"/>
    <parent link="base_link"/>
    <child link="depth_cam"/>
    <axis xyz="0 0 0"/>
  </joint>
  <link name="lidar_frame">
    <inertial>
      <origin rpy="0 0 0" xyz="8.65086404290248E-05 9.02624664517182E-05 -0.0183546134707293"/>
      <mass value="0.0405423044439003"/>
      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
    </inertial>
    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
  </link>
  <joint name="lidar_Joint" type="fixed">
    <origin rpy="0 0 0" xyz="-0.012242 -8.533E-05 0.092501"/>
    <parent link="base_link"/>
    <child link="lidar_frame"/>
    <axis xyz="0 0 0"/>
  </joint>
  
</robot>

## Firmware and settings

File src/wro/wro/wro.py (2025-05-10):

#!/usr/bin/env python3
# encoding: utf-8
import os
import os.path
import cv2 as cv
import math
import queue
import rclpy
import matplotlib.pyplot as plt
from math import cos, sin, radians, pi, atan2, tan # Added atan2, tan
import time
import threading
import numpy as np

from rclpy.node import Node
from cv_bridge import CvBridge
from sensor_msgs.msg import Image
from geometry_msgs.msg import Twist
from sensor_msgs.msg import LaserScan
from std_srvs.srv import SetBool, Trigger
from ros_robot_controller_msgs.msg import SetPWMServoState, PWMServoState # Simplified imports
from rclpy.qos import QoSProfile, QoSReliabilityPolicy, QoSDurabilityPolicy

from .lidar import LidarResult
from .control import Control
from .start import is_ready



class OjbectTrackingNode(Node):
    def __init__(self, name):
        self.__node_name = name
        super().__init__(name, allow_undeclared_parameters=True, automatically_declare_parameters_from_overrides=True)
        self.get_logger().info(f"Initializing node '{self.__node_name}'...")

        self.set_callback = False
        self.is_running = False

        self.lock = threading.RLock() # General lock
        self.image_sub = None
        self.result_image = None
        self.image_height = None
        self.image_width = None
        self.bridge = CvBridge()

        self.mecanum_pub = self.create_publisher(Twist, '/controller/cmd_vel', 1)
        self.servo_state_pub = self.create_publisher(SetPWMServoState, 'ros_robot_controller/pwm_servo/set_state', 1)

        lidar_qos = QoSProfile(
             depth=1,
             reliability=QoSReliabilityPolicy.BEST_EFFORT, # Or RELIABLE
             durability=QoSDurabilityPolicy.VOLATILE)
        self.lidar_sub = self.create_subscription(LaserScan, '/scan_raw', self.lidar_callback, lidar_qos)

#        self.position = np.array([0.5, 0.5]) # Initial estimated position (e.g., near corner)
#        self.rotation = np.radians(45.0) # Initial estimated orientation
        self.pose_lock = threading.Lock() # Lock specifically for pose variables
        self.position_history = [] # Keep if needed for plotting paths

        # Last commanded/intended controls (used for MCL prediction)
        self.current_velocity = 0.0
        self.current_steering_angle = 0.0 # In radians


        # --- Visualization Setup ---
        plt.figure() # Create figure for animation
        plt.ion() # Turn on interactive mode
        plt.show() # Show the plot window

        self.get_logger().info('\033[1;32mNode initialized successfully.\033[0m')

        self.control = Control(self.get_logger())        
        
        # delta time in seconds
        self.dt = 0
        self.prev_time = time.time()
        
        self.start_time = 0
        

    def log(self, msg):
        self.get_logger().info('\033[1;32m%s\033[0m' % msg)

    def publish_servo_state(self, positions):
        # Ensure positions are integers
        int_positions = [int(p) for p in positions]
        servo_state = PWMServoState()
        servo_state.id = [3] # servo ID 3 for steering
        servo_state.position = int_positions # Use integer positions
        data = SetPWMServoState()
        data.state = [servo_state]
        data.duration = 1 / 333 # Use float for duration
        # self.get_logger().info(f'Publishing servo state: {data}') # Can be verbose
        self.servo_state_pub.publish(data)

    def steer(self, direction):
        """
        Sets the steering command based on direction (-1 to 1).
        """
        direction = max(-1.0, min(1.0, float(direction))) # Ensure float and clamp

        self.current_steering_angle = direction

        max_steer_offset = 500 # Servo range offset
        norm_dir_servo = 1500 # Servo center value
        
        # more minus = more left
        correction = 90
        
        new_angle_servo = norm_dir_servo + direction * -max_steer_offset + correction
        self.publish_servo_state([int(new_angle_servo)]) # Send command to servo

    def set_speed(self, speed):
        """
        Sets the linear velocity command.
        """
        with self.lock: # Use general lock or a specific control lock
            # Assuming speed argument IS the desired velocity in m/s
            # Clamp if necessary based on robot limits
            self.current_velocity = speed
            # self.get_logger().info(f"Commanded velocity: {self.current_velocity:.2f} m/s")

            # --- Publish Twist Command ---
            t = Twist()
            # Use the *intended* velocity for the command, even if MCL uses a slightly different internal value
            # The sign convention might need adjustment based on your controller setup
            t.linear.x = float(-speed) # Send original requested speed value
            self.mecanum_pub.publish(t)

    def image_callback(self, ros_image):
        pass

    


    def plot_lidar(self, lidar_data):
        angles = np.linspace(lidar_data.angle_min, lidar_data.angle_max, len(lidar_data.ranges))
        distances = np.array(lidar_data.ranges)
        distances = np.where(np.isnan(distances), 0, distances)
        distances = np.where(np.isinf(distances), 0, distances)
        distances = np.where(distances > 3, 0, distances)
        distances = np.where(distances < 0.1, 0, distances)
        
        mask = distances != 0
        distances = distances[mask]
        angles = angles[mask]
        
        angles = angles + np.pi
                
        oy = np.cos(angles) * distances
        ox = -np.sin(angles) * distances
        scan = np.column_stack((ox, oy))
        
        plt.cla()
        plt.grid(True)
        plt.xlim((3, -3)) # rescale y axis, to match the grid orientation
        plt.ylim((-3, 3)) # rescale y axis, to match the grid orientation
        plt.scatter(ox, oy, s=2, c="blue") # lines from 0,0 to the
        plt.xlabel("X")
        plt.ylabel("Y")

        plt.pause(0.0001)

 
        self.last_laser_scan = scan
         

    def lidar_callback(self, lidar_data):
        if is_ready() == False:
            return
        
        self.lidar_result = LidarResult(lidar_data)
        
        self.dt = time.time() - self.prev_time
        self.prev_time = time.time()
        

        self.control.update_lidar(lidar_data)
        speed, stearing = self.control.get_control_strategy()
        
        self.set_speed(speed)
        self.steer(stearing)
        
        #self.plot_lidar(lidar_data)
        
        return
        
        angles = np.linspace(lidar_data.angle_min, lidar_data.angle_max, len(lidar_data.ranges))
        distances = np.array(lidar_data.ranges)
        distances = np.where(np.isnan(distances), 0, distances)
        distances = np.where(np.isinf(distances), 0, distances)
        distances = np.where(distances > 3, 0, distances)
        distances = np.where(distances < 0.1, 0, distances)
        
        mask = distances != 0
        ranges = distances[mask]
        angles = angles[mask]
    
        rot_drift = np.clip(rot_drift, -20, 20)
    
        frame_count += 1
        current_time = frame_count * DT

        # --- Simple Example Control Logic ---
        # Drive forward, turn slightly left initially, then maybe turn right
        velocity_cmd = 0.3 # m/s
        steering_cmd = 0.0 # radians
        
        color, (obstacle_distance, obstacle_angle) = detect_block(None)

        if color is not None:
            print(f"Obstacle ({color}) distance: {obstacle_distance:.2f} m, angle: {math.degrees(obstacle_angle):.1f}°")


        distance_to_front = ranges[round(len(ranges) / 2)]
        distance_to_left = ranges[-round(len(ranges) / 8)]
        distance_to_right = ranges[round(len(ranges) / 8)]

        distance_to_left_l = ranges[-round(len(ranges) / 8) + 8]
        distance_to_left_r = ranges[-round(len(ranges) / 8) - 8]


        distance_to_front_l = ranges[round(len(ranges) / 2) + 8]
        distance_to_front_r = ranges[round(len(ranges) / 2) - 8]
        
        distance_to_right_l = ranges[round(len(ranges) / 8) + 8]
        distance_to_right_r = ranges[round(len(ranges) / 8) - 8]
        
        if state == "MOVING":
            if rot_drift > 1:
                steering_cmd = -1
                rot_drift -= 1
            elif rot_drift < -1:
                steering_cmd = 1
                rot_drift += 1
                    
            print(f"Moving dist left: {distance_to_left}")
            if obstacle_distance is not None and obstacle_distance < 0.5:
                print(f"CHANGING STATE: MOVING -> OBSTACLE_AVOIDANCE")
                rot_drift /= 3
                state = "OBSTACLE_AVOIDANCE"
                steering_cmd = 1
            
            elif distance_to_front < 0.8 and obstacle_distance is None and max(distance_to_left, distance_to_left_l, distance_to_left_r) > 0.8 and max(distance_to_right, distance_to_right_l, distance_to_right_r) < 1:
                print(f"CHANGING STATE: MOVING -> TURNING")
                state = "TURNING"
                steering_cmd = 1

        if state == "OBSTACLE_AVOIDANCE":
            print(f"OBSTACLE_AVOIDANCE: angle={obstacle_angle} distance={obstacle_distance} rot_drift={rot_drift}")
            if obstacle_distance is None:
                print(f"CHANGING STATE: OBSTACLE_AVOIDANCE -> MOVING")
                state = "MOVING"
                steering_cmd = 0
            elif obstacle_distance < 0.2 and not ((obstacle_angle > 0.7 and color == "red") or (obstacle_angle < -0.7 and color == "green")):
                print(f"CHANGING STATE: OBSTACLE_AVOIDANCE -> OBSTACLE_AVOIDANCE_PANIC")
                state = "OBSTACLE_AVOIDANCE_PANIC"
            else:
                if color == "red" and obstacle_angle < 0.7:
                    steering_cmd = -1
                    rot_drift -= 1.25
                elif color == "green" and obstacle_angle > -0.7:
                    steering_cmd = 1
                    rot_drift += 1.25

        if state == "OBSTACLE_AVOIDANCE_PANIC":
            print(f"OBSTACLE_AVOIDANCE_PANIC: angle={obstacle_angle} distance={obstacle_distance} rot_drift={rot_drift}")
            if obstacle_distance is None:
                print(f"CHANGING STATE: OBSTACLE_AVOIDANCE_PANIC -> MOVING")
                state = "MOVING"
            elif obstacle_distance > 0.5:
                print(f"CHANGING STATE: OBSTACLE_AVOIDANCE_PANIC -> OBSTACLE_AVOIDANCE")
                state = "OBSTACLE_AVOIDANCE"
            else:
                velocity_cmd = -0.3
                if obstacle_angle > 0.2:
                    steering_cmd = 0.2
                    rot_drift += 0.2
                elif obstacle_angle < -0.2:
                    steering_cmd = -0.2
                    rot_drift -= 0.2
                

        if state == "TURNING":
            print(f"TURNING: {prev_dist_front=} {distance_to_front=}")
            if abs(distance_to_front_r - distance_to_front_l) < 0.15:
                print(f"CHANGING STATE: TURNING -> MOVING")
                state = "MOVING"
                steering_cmd = 0
            if obstacle_distance is not None and obstacle_distance < 0.5:
                print(f"CHANGING STATE: TURNING -> OBSTACLE_AVOIDANCE")
                state = "OBSTACLE_AVOIDANCE"
                velocity_cmd = 0.3
            else:
                steering_cmd = 1


        print("Steering command:", math.degrees(steering_cmd))
        print("Velocity command:", velocity_cmd)

        prev_dist_front = distance_to_front

        self.steer(steering_cmd)
        self.set_speed(velocity_cmd)        
        

def main(args=None):
    rclpy.init(args=args)
    node = None
    try:
        node = OjbectTrackingNode('wro') # Renamed node
        rclpy.spin(node)
    except KeyboardInterrupt:
        print("Ctrl+C detected, shutting down.")
    except Exception as e:
        raise e
        if node:
             node.get_logger().fatal(f"Unhandled exception: {e}")
        else:
             print(f"Exception during node creation: {e}")
    finally:
        if node:
            node.destroy_node()
        if rclpy.ok():
            rclpy.shutdown()
        print("Shutdown complete.")


if __name__ == "__main__":
    main()

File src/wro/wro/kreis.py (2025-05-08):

#!/usr/bin/env python3
# encoding: utf-8
# ????(color tracking)
import os
import os.path
import cv2 as cv
import math
import queue
import rclpy
import matplotlib.pyplot as plt
from math import cos, sin, radians, pi
import time
import threading
import numpy as np
import sdk.pid as pid
import sdk.common as common
from rclpy.node import Node
from cv_bridge import CvBridge
from sensor_msgs.msg import Image
from geometry_msgs.msg import Twist
from sensor_msgs.msg import LaserScan
from std_srvs.srv import SetBool, Trigger
from interfaces.srv import SetPoint, SetFloat64
from ros_robot_controller_msgs.msg import MotorsState, SetPWMServoState, PWMServoState
from rclpy.qos import QoSProfile, QoSReliabilityPolicy
from nav_msgs.msg import Odometry
from sklearn.cluster import DBSCAN
from sklearn.linear_model import RANSACRegressor



class OjbectTrackingNode(Node):
    def __init__(self, name):
        rclpy.init()
        super().__init__(name, allow_undeclared_parameters=True, automatically_declare_parameters_from_overrides=True)
        self.name = name
        self.set_callback = False
        self.color_picker = None
        self.tracker = None
        self.is_running = False
        self.threshold = 0.1
        self.dist_threshold = 0.3
        self.lock = threading.RLock()
        self.image_sub = None
        self.result_image = None
        self.image_height = None
        self.image_width = None
        self.bridge = CvBridge()

        self.mecanum_pub = self.create_publisher(Twist, '/controller/cmd_vel', 1)
        self.servo_state_pub = self.create_publisher(SetPWMServoState, 'ros_robot_controller/pwm_servo/set_state', 1)
        self.get_logger().info('\033[1;32m%s\033[0m' % 'start')

        self.steer(0)
        self.set_speed(0.5)
        
        
    def log(self, msg):
        self.get_logger().info('\033[1;32m%s\033[0m' % msg)

    def get_node_state(self, request, response):
        response.success = True
        return response
    
    def publish_servo_state(self, positions):
        servo_state = PWMServoState()
        servo_state.id = [3]
        servo_state.position = positions
        data = SetPWMServoState()
        data.state = [servo_state]
        data.duration = 1 / 333
        self.get_logger().info(f'Publishing servo state: {data}')
        self.servo_state_pub.publish(data)


    def steer(self, direction):
        """
        direction: 1 = left, -1 = right
        """
        direction = max(-1, min(1, direction))

        max_steer = 300
        norm_dir = 1500
        correction = -50
        
        # smaller = rechts
        
        new_angle = norm_dir + direction * -max_steer + correction

        
        self.publish_servo_state([int(new_angle)])
        self.get_logger().info(f'Steering to {new_angle}')

    def set_speed(self, speed):
        """
        speed: -1 to 1
        """
        speed = - speed
        speed = max(-1, min(1, speed))
        
        t = Twist()
        t.linear.x = float(speed)
        self.mecanum_pub.publish(t)
        
def main():
    node = OjbectTrackingNode('object_tracking')
    rclpy.spin(node)
    node.destroy_node()
    rclpy.shutdown()

if __name__ == "__main__":
    main()

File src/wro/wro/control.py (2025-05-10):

# ros uses relative imports
import sys
import time
import numpy as np


try:
    from .lidar import LidarResult
except:
    from lidar import LidarResult

"""
Important Note:
stearing: 
0 = front
-1 = left
+1 = right

"""
class Control:
    def __init__(self, logger=None):
        self.lidar_res = LidarResult()
        self.state = "MOVING"
        
        self.logger = None
        if logger is not None:
            self.logger = logger
            
        """
        TURNING variables
        """
        # RIGHT | LEFT
        self.turning_direction = ""
        
        self.time_start = 0
     
    def log(self, msg):
        if self.logger:
            self.logger.info('\033[1;32m%s\033[0m' % msg)
        else:
            print(msg)
        
    def update_lidar(self, raw_data):
        self.lidar_res = LidarResult(raw_data)

    def update_odom(self, odom_data):
        pass
    
    def change_state(self, new_state):
        if new_state not in ["MOVING", "TURNING"]:
            raise ValueError(f"Invalid state: {new_state}")
        
        self.log(f"STATE CHANGE: {self.state} -> {new_state}")

        if new_state == "TURNING":
            distance_left = self.lidar_res.get_distance_for_angle(-np.pi/2)
            distance_right = self.lidar_res.get_distance_for_angle(np.pi/2)
            
            if self.turning_direction == "":
                if distance_left < distance_right:
                    self.log("TURNING: DIRECTION CALCULATED: LEFT")
                    self.turning_direction = "LEFT"
                else:
                    self.log("TURNING: DIRECTION CALCULATED: RIGHT")
                    self.turning_direction = "RIGHT"
                
        self.state = new_state
    
    def get_control_strategy(self):
        """
        Returns speed and steering direction
        """
        if self.time_start == 0:
            self.time_start = time.time()
        
        speed = 0.5
        stear = 0
        """
        ---------------------------------------
        MOVING Strategy
        ---------------------------------------
        """
        MIN_DISTANCE_TO_WALL = 0.8

        if self.state == "MOVING":
            stear = 0
            
            """
            Strategy change
            """
            distance_to_front = self.lidar_res.get_distance_for_angle(0)
            self.log(f"MOVING: Distance: F{distance_to_front:.3f}")

            if distance_to_front < MIN_DISTANCE_TO_WALL:
                self.change_state("TURNING")

        
        """
        ---------------------------------------
        TURNING Strategy
        ---------------------------------------
        """
        TURN_UNTIL_DISTANCE_GREATER = 2
        TURN_UNTIL_ANGLE_SMALLER = 0.2
        
        if self.state == "TURNING":
            angle_to_dir = 0
            distance_to_dir = 0
            if self.turning_direction == "RIGHT":
                stear = 1
                angle_to_dir = self.lidar_res.get_angle_to_wall(np.pi / 2)
                distance_to_dir = self.lidar_res.get_median_distance_for_angle(np.pi / 2)
            elif self.turning_direction == "LEFT":
                stear = -1
                angle_to_dir = self.lidar_res.get_angle_to_wall(-np.pi / 2)
                distance_to_dir = self.lidar_res.get_median_distance_for_angle(-np.pi / 2)
                
            med_distance_to_front = self.lidar_res.get_median_distance_for_angle(0)
            angle_to_front = self.lidar_res.get_angle_to_wall(0)
        
            self.log(f"TURNING: Angle: F:{angle_to_front:.3f} D:{angle_to_dir:.3f} | Distance: F:{med_distance_to_front:.3f} D:{distance_to_dir:.3f}")
            if angle_to_front < TURN_UNTIL_ANGLE_SMALLER:
                self.change_state("MOVING")

        self.log(f"SPEED: {speed} STEAR: {stear}")
        
        if abs(self.time_start - time.time()) > 52:
            speed = 0
        
        return speed, stear

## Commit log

2025-03-10 Add mentor pi sample code
    [ack.xacro, back_shell_black_link.stl, back_shell_black_link_collision.stl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]
2025-05-06 change folder structure - move everything ros into src/
    [ack.xacro, back_shell_black_link.stl, back_shell_black_link_collision.stl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]
2025-05-06 Add lidar pictures
2025-05-07 code for camera
2025-05-07 Adjust README:
    - Problem Statement and Goal
    - Add Vehicle Photos
    - Update Hardware changes
    - Add lego differential gearbox
    - Add Sensor Overview
    - Add Obstacle detection with OpenCV (Guilherme)
2025-05-08 README: Adjust size of lidar picture
2025-05-08 README: Adjust size of motor construct picture
2025-05-10 update to final code and add 3d models
    [LidarMountingPlate.step, LidarMountingPlate.stl, ReplacementBasePlateLidar.step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]
